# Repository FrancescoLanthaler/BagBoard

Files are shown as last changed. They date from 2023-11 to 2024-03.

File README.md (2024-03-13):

# BagBoard

A cool macropad with an easy interface to allow you to change the keybinds to whatever you want!

## Get started:
First of all you will need the pcb and all the components.
Then you will need to install the libs and the main.py code.

### Web Interface:
https://bagboard.francescolanthaler.com/

#### Change Keypad Layout:
Inside the web interface you can reassign each Key to a specific value. 
If you want a key to output a string just use the *custom* option

To change the Layout then copy the code from the interface and replace the one in *main.py*

```python
keys_pressed = [Keycode.TWO, Keycode.A, Keycode.A, Keycode.FOUR, Keycode.FIVE, Keycode.SIX, Keycode.B, Keycode.SEVEN, Keycode.EIGHT, Keycode.NINE, Keycode.C, Keycode.PERIOD, Keycode.ZERO, Keycode.ENTER, Keycode.D]
rotary_pressed = ConsumerControlCode.PLAY_PAUSE
```

#### Change Animation:
To change the Gif just download one from any website or use a URL (has to be a "drawing" and it works best if black and white).
Then upload them to the site and when downloading it put it into the icons folder.

In the main.py change the file name and number of frame to the new ones:

```python
FRAMES = 9
IMAGE_FILE = "/icons/FILENAMEHERE.bmp".format(0)
```

## License:

Copyright 2024 Francesco Lanthaler
This project includes code from libraries that are licensed under various open-source licenses.

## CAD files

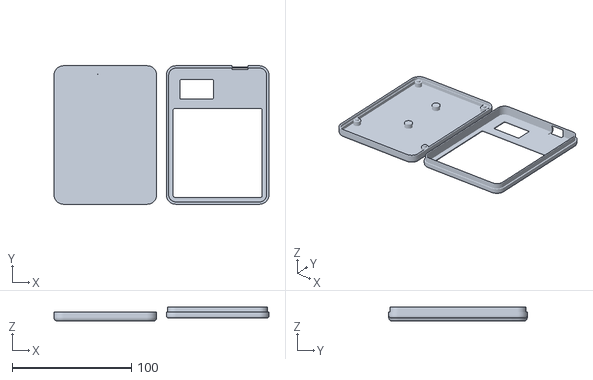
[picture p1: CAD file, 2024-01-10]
3d-files/macropad_case.stl
180.0 x 116.0 x 12.1

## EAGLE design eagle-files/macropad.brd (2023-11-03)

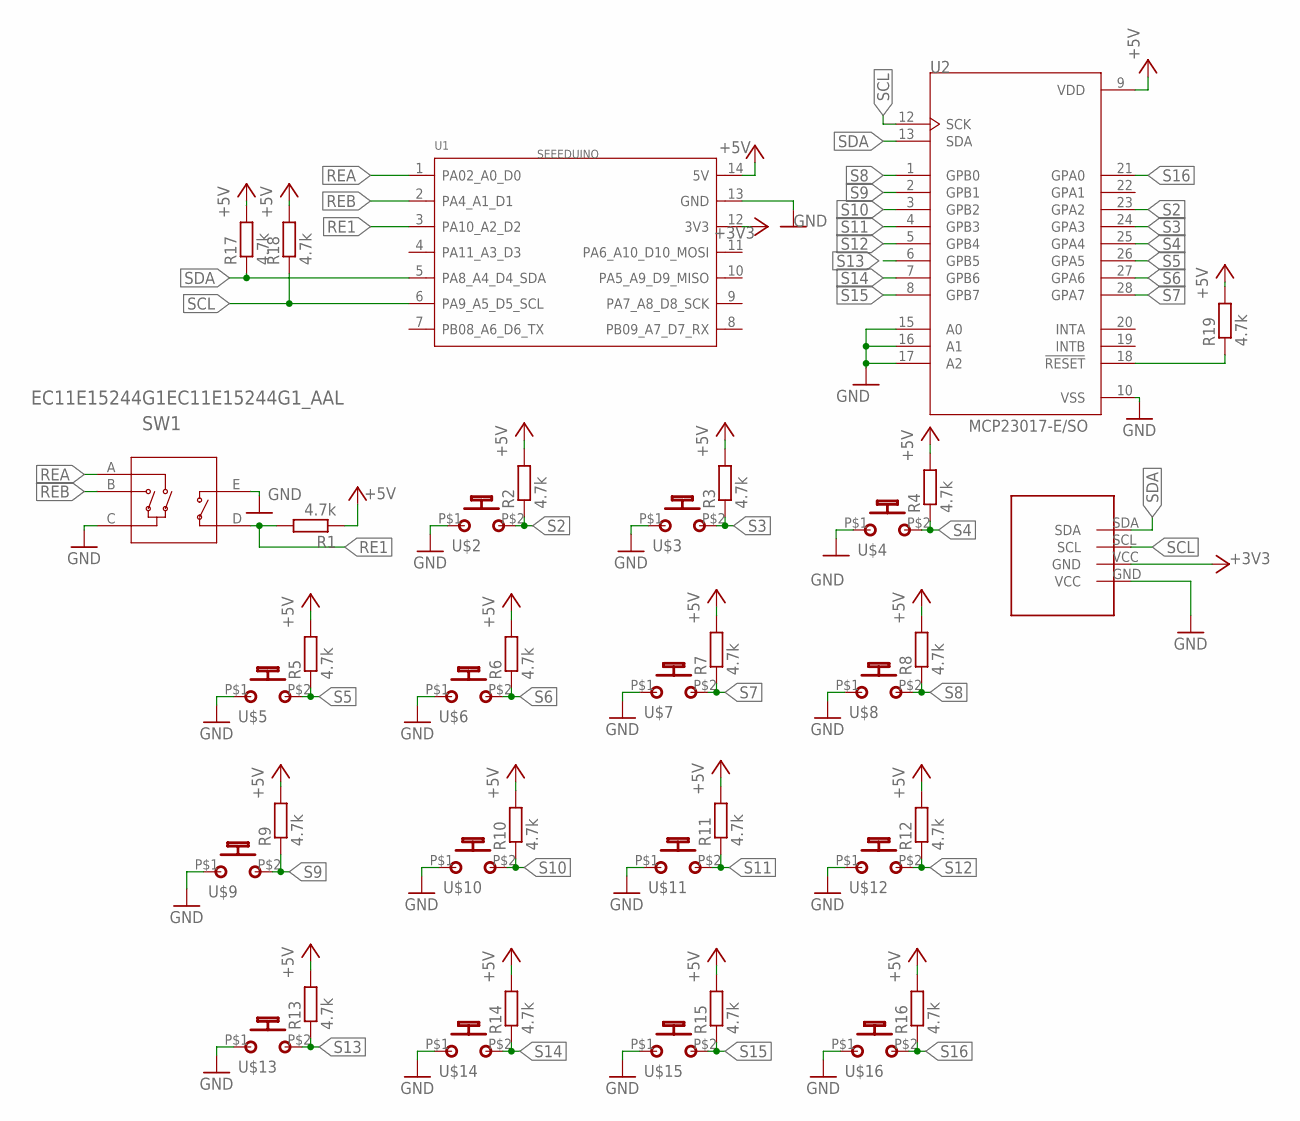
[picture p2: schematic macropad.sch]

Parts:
DISPLAY: OLED_0.96_I2C
R1, R2, R3, R4, R5, R6, R7, R8, R9, R10, R11, R12, R13, R14, R15, R16, R17, R18, R19: 4.7k; R0805
SW1: EC11E15244G1EC11E15244G1_AAL; EC11E15244G1_AAL
U1: SEEEDUINO; MOUDLE14P-2.54-21X17.8MM
U2: MCP23017-E/SO; SOIC127P1030X265-28N
U$2, U$3, U$4, U$5, U$6, U$7, U$8, U$9, U$10, U$11, U$12, U$13, U$14, U$15, U$16: MX1A-11NN; CHERRY_MX1A-11NN_SWITCH

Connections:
+3V3: DISPLAY.VCC (GND), U1.12 (3V3)
+5V: R1.1, R2.2, R3.2, R4.2, R5.2, R6.2, R7.2, R8.2, R9.2, R10.2, R11.2, R12.2, R13.2, R14.2, R15.2, R16.2, R17.2, R18.2, R19.2, U1.14 (5V), U2.9 (VDD)
GND: DISPLAY.GND (VCC), SW1.C, SW1.E, U1.13 (GND), U2.10 (VSS), U2.15 (A0), U2.16 (A1), U2.17 (A2), U$2.P$1, U$3.P$1, U$4.P$1, U$5.P$1, U$6.P$1, U$7.P$1, U$8.P$1, U$9.P$1, U$10.P$1, U$11.P$1, U$12.P$1, U$13.P$1, U$14.P$1, U$15.P$1, U$16.P$1
unnamed: R19.1, U2.18 (!RESET)
RE1: R1.2, SW1.D, U1.3 (PA10_A2_D2)
REA: SW1.A, U1.1 (PA02_A0_D0)
REB: SW1.B, U1.2 (PA4_A1_D1)
S2: R2.1, U2.23 (GPA2), U$2.P$2 (S)
S3: R3.1, U2.24 (GPA3), U$3.P$2 (S)
S4: R4.1, U2.25 (GPA4), U$4.P$2 (S)
S5: R5.1, U2.26 (GPA5), U$5.P$2 (S)
S6: R6.1, U2.27 (GPA6), U$6.P$2 (S)
S7: R7.1, U2.28 (GPA7), U$7.P$2 (S)
S8: R8.1, U2.1 (GPB0), U$8.P$2 (S)
S9: R9.1, U2.2 (GPB1), U$9.P$2 (S)
S10: R10.1, U2.3 (GPB2), U$10.P$2 (S)
S11: R11.1, U2.4 (GPB3), U$11.P$2 (S)
S12: R12.1, U2.5 (GPB4), U$12.P$2 (S)
S13: R13.1, U2.6 (GPB5), U$13.P$2 (S)
S14: R14.1, U2.7 (GPB6), U$14.P$2 (S)
S15: R15.1, U2.8 (GPB7), U$15.P$2 (S)
S16: R16.1, U2.21 (GPA0), U$16.P$2 (S)
SCL: DISPLAY.SCL, R18.1, U1.6 (PA9_A5_D5_SCL), U2.12 (SCK)
SDA: DISPLAY.SDA, R17.1, U1.5 (PA8_A4_D4_SDA), U2.13 (SDA)

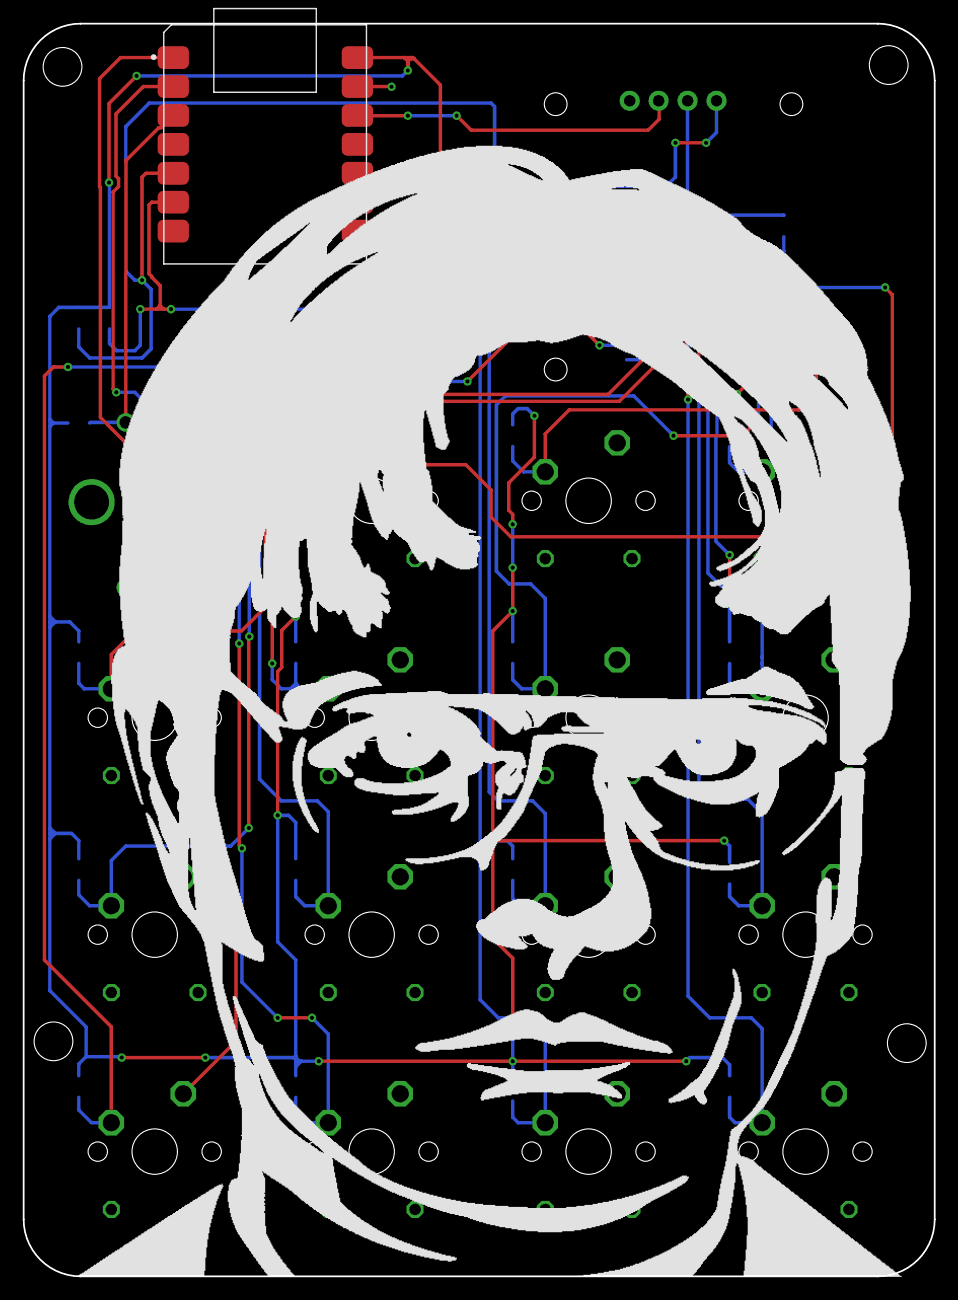
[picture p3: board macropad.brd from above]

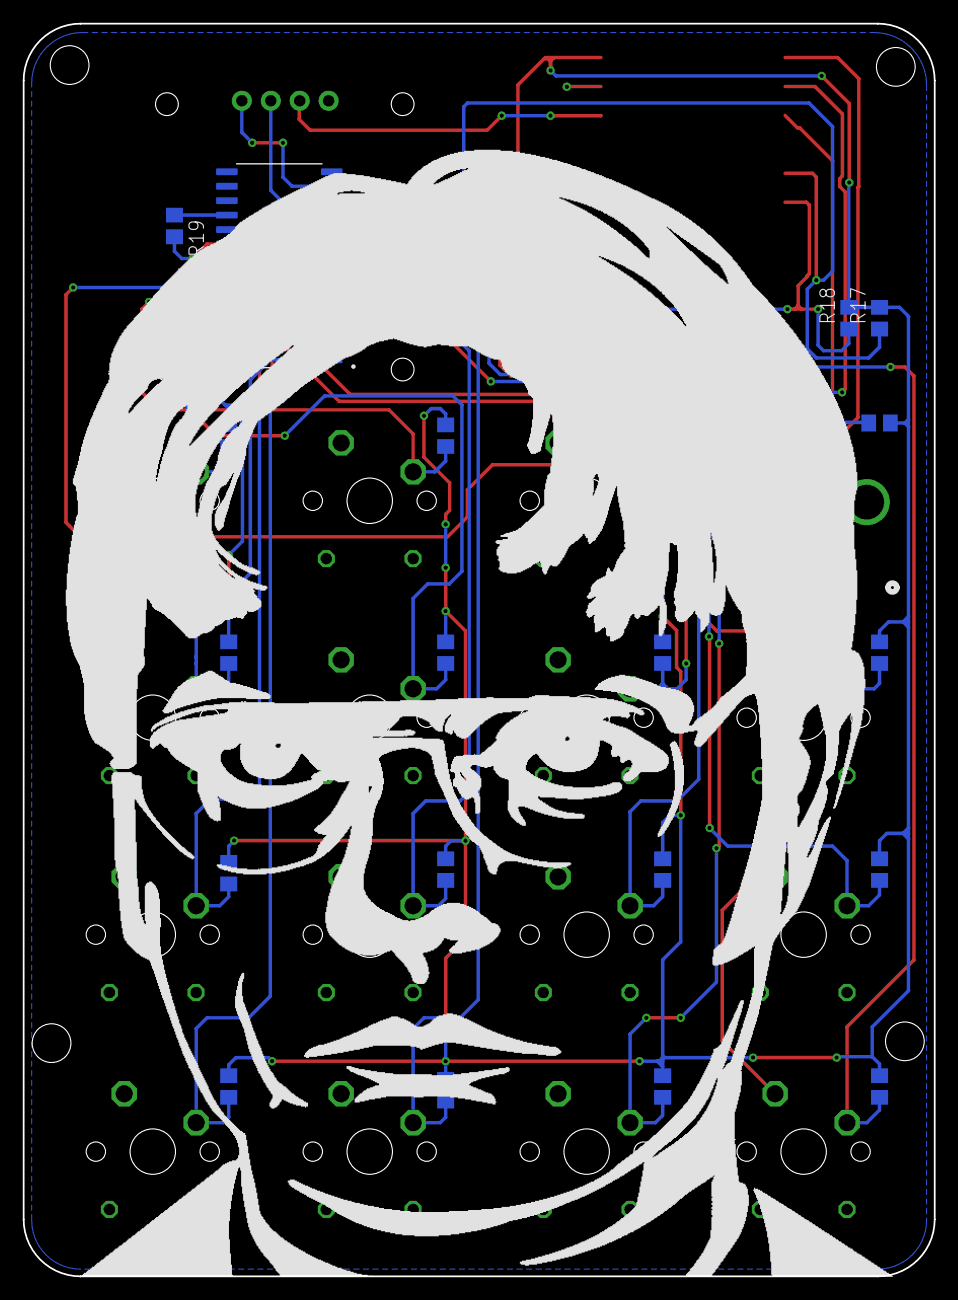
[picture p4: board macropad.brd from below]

Board: 2 copper layers, 80.0 x 110.0 mm, 38 parts (20 on the bottom side), 24 nets.

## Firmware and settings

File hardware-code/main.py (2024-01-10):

import time
import board
import busio
import digitalio
import usb_hid
import displayio
import rotaryio
import adafruit_displayio_ssd1306
import adafruit_imageload
from adafruit_mcp230xx.mcp23017 import MCP23017
from adafruit_hid.keyboard import Keyboard
from adafruit_hid.keyboard_layout_us import KeyboardLayoutUS
from adafruit_hid.keycode import Keycode
from adafruit_hid.consumer_control import ConsumerControl
from adafruit_hid.consumer_control_code import ConsumerControlCode

displayio.release_displays()


## CONFIGURATION ##
# Keys
keys_pressed = [
    Keycode.TWO,
    Keycode.THREE,
    Keycode.A,
    Keycode.FOUR,
    Keycode.FIVE,
    Keycode.SIX,
    Keycode.B,
    Keycode.SEVEN,
    Keycode.EIGHT,
    Keycode.NINE,
    Keycode.C,
    Keycode.PERIOD,
    Keycode.ZERO,
    Keycode.ENTER,
    Keycode.D,
]
rotary_pressed = ConsumerControlCode.PLAY_PAUSE

# Animation
FRAMES = 9
IMAGE_FILE = "/icons/icon_9_frames.bmp"

## END CONFIGURATION ##

# Create I2C things
i2c = busio.I2C(board.SCL, board.SDA)
display_bus = displayio.I2CDisplay(i2c, device_address=0x3C)
display = adafruit_displayio_ssd1306.SSD1306(display_bus, width=128, height=64)
mcp = MCP23017(i2c)
encoder = rotaryio.IncrementalEncoder(board.D0, board.D1)

# Rotary Encoder Button
button = digitalio.DigitalInOut(board.D2)
button.direction = digitalio.Direction.INPUT
button.pull = digitalio.Pull.UP
button_state = None
last_position = encoder.position


# Array of key objects
keypress_pins = [mcp.get_pin(i) for i in range(2, 16)] + [mcp.get_pin(0)]
key_pin_array = []

time.sleep(1)  # Sleep for a bit to avoid a race condition on some systems

# Create a keyboard object
keyboard = Keyboard(usb_hid.devices)
consumer = ConsumerControl(usb_hid.devices)
keyboard_layout = KeyboardLayoutUS(keyboard)

# Make all pin objects inputs with pullups
for pin in keypress_pins:
    pin.direction = digitalio.Direction.INPUT
    pin.pull = digitalio.Pull.UP
    key_pin_array.append(pin)

# Initialize key states to False
key_state = [False] * len(key_pin_array)


FRAME_SIZE = (64, 64)
group = displayio.Group()
bits, colors = adafruit_imageload.load(
    IMAGE_FILE, bitmap=displayio.Bitmap, palette=displayio.Palette
)
colors[0], colors[1] = colors[1], colors[0]  # Swap black and white

grid = displayio.TileGrid(
    bits,
    pixel_shader=colors,
    width=1,
    height=1,
    tile_height=FRAME_SIZE[1],
    tile_width=FRAME_SIZE[0],
    default_tile=0,
    x=32,
    y=0,
)

group.append(grid)
display.show(group)

framerate = 0
frame = 0

CHANGING_VOLUME = False
timer_volume = 0

print("Waiting for key pin...")
while True:
    # Rotary Encoder
    current_position = encoder.position
    position_change = current_position - last_position

    if position_change > 0:
        CHANGING_VOLUME = True
        timer_volume = time.monotonic()
        for _ in range(position_change):
            consumer.send(ConsumerControlCode.VOLUME_INCREMENT)
    elif position_change < 0:
        CHANGING_VOLUME = True
        for _ in range(-position_change):
            consumer.send(ConsumerControlCode.VOLUME_DECREMENT)

    last_position = current_position
    if CHANGING_VOLUME and (timer_volume + 1) < time.monotonic():
        CHANGING_VOLUME = False
        print("Volume change ended.")

    if not button.value and button_state is None:
        button_state = "pressed"
    if button.value and button_state == "pressed":
        print("Button pressed.")
        consumer.send(rotary_pressed)
        button_state = None

    # Keyboard

    if not CHANGING_VOLUME:
        for i, key_pin in enumerate(key_pin_array):
            if not key_pin.value:
                if not key_state[i]:  # Has the key not been pressed yet for this pin?
                    key_state[i] = True  # Set key state to pressed
                    print("Pin #%d is grounded." % i)

                    key = keys_pressed[i]
                    if isinstance(key, str):
                        keyboard_layout.write(key)
                    else:
                        keyboard.press(key)
                        keyboard.release_all()

            else:  # If it's not grounded
                key_state[i] = False  # Reset key state when ungrounded

    # Display
    if not CHANGING_VOLUME:
        if (framerate + 0.1) < time.monotonic():
            grid[0] = frame
            frame += 1
            framerate = time.monotonic()
            if frame > FRAMES - 1:
                frame = 0

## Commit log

2023-11-02 Fixed many things and expanded web interface to convert images
    [main.py]
2023-11-03 organized files in subfolders
    [macropad.brd, macropad.sch]
2023-11-04 Fixed issues with animation etc.
    [main.py]
2024-01-10 added 3d files for case
    [macropad_case.stl]

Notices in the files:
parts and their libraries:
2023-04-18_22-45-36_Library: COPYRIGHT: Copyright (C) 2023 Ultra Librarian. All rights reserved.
